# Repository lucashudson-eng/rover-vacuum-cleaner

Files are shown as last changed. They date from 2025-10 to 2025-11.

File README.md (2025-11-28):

# rover

Autonomous robotic rover designed for navigation and task execution, inspired by smart vacuum cleaners.

## Main Components

- [BTT PI 2](https://pt.aliexpress.com/item/1005006869449371.html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)
- [ESP32-S3 Nano](https://pt.aliexpress.com/item/1005007291319086.html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)
- [Lidar 2D 360º LD14P](https://pt.aliexpress.com/item/1005008670123046.html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)
- [N20 DC Motor 6V 500RPM w/ Magnetic Encoders](https://pt.aliexpress.com/item/1005004999529855.html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)
- [Pololu Motor Driver TB6612FNG](https://www.pololu.com/product/713)
- [IMU 6-DOF MPU-6050](https://pt.aliexpress.com/item/1005008569435439.html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)
- [Wheels 65mm](https://pt.aliexpress.com/item/1005005293126427.html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)
- [Chassi 4WD](https://pt.aliexpress.com/item/1005007026658421.html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)
- [Camera OV5647](https://pt.aliexpress.com/item/1005006279352733.html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)
- [3x ToF VL53L1X/TOF400C](https://pt.aliexpress.com/item/1005009534829792.html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)
- [I2C Multiplexer TCA9548A](https://pt.aliexpress.com/item/1005004996004241.html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)
- [Buck Step Down 6V 2.2A LM317](https://pt.aliexpress.com/item/1005006299002383.html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)
-  [I2C Power Monitoring INA219](https://pt.aliexpress.com/item/1005007533576335.html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)
- Battery 3s 2500mah

## Auxiliary Components

- [2P/4P/5P/6P JST 2.54mm Right Angle Pin Connector](https://pt.aliexpress.com/item/33008489410.html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)
- [2P/4P/5P/6P JST 2.54mm Housing](https://pt.aliexpress.com/item/1005007449862216.html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)
- [4P JST 2.54mm Extension Line](https://pt.aliexpress.com/item/1005007492397255.html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)
- [Battery Velcro Strap](https://shopee.com.br/Cinta-Correia-Velcro-Para-Bateria-Lipo-Drone-Aeromodelo-automodelo-25cm-i.389375152.9818950596)
- [PCB Universal Board Single Sid 7x9cm](https://pt.aliexpress.com/item/1005007720411113.html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)
- [PTH Resistors 1/4W 3.3K/6.2K/10K](https://pt.aliexpress.com/item/32968455454.html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)
- [M2.5/M3 Hex Nylon Standoff Spacer](https://pt.aliexpress.com/item/32862529967.html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)
- [12V Round Rocker Switch LED](https://pt.aliexpress.com/item/1005007561730939.html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)
- [N20 Motor Mount](https://pt.aliexpress.com/item/1005007027114123.html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)

## Pinout

### Battery
- Cell 1 - A0 (GPIO1)
- Cell 1+2 - A1 (GPIO2)

### ISR

- 3xVL6180X - A2 (GPIO3)
- MPU6050 - A3 (GPIO4)
- Motor Encoder Back Left C1 - D2 (GPIO5)
- Motor Encoder Back Left C2 - D3 (GPIO6)
- Motor Encoder Back Right C2 - D4 (GPIO7)
- Motor Encoder Back Right C1 - D5 (GPIO8)

### Motor Driver

- PWMA - D6 (GPIO8)
- AIN2 - D7 (GPIO9)
- AIN1 - D8 (GPIO10)
- STBY - D9 (GPIO18)
- BIN1 - D10 (GPIO21)
- BIN2 - D11 (GPIO38)
- PWMB - D12 (GPIO47)

### I2C (MPU6050, TCA9548A (3xVL6180X), INA219)

- SDA - A4 (GPIO11)
- SCL - A5 (GPIO12)

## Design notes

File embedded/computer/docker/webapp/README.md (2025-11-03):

# Rover Vacuum Cleaner - Sistema Embarcado

Sistema web embarcado para controle de rover aspirador autônomo, desenvolvido com React + Vite no frontend e Flask no backend, otimizado para recursos limitados.

## Estrutura do Projeto

```
webapp/
├── frontend/          # Aplicação React + Vite
│   ├── src/           # Código fonte React
│   │   ├── components/ # Componentes React
│   │   ├── App.jsx    # Componente principal
│   │   └── main.jsx   # Ponto de entrada
│   ├── public/        # Arquivos estáticos
│   ├── package.json   # Dependências React
│   ├── server.js     # Servidor Express para produção
│   └── vite.config.js # Configuração Vite
├── backend/           # API Flask
│   ├── requirements.txt # Dependências Python
│   └── app.py         # API Flask
├── Dockerfile         # Build otimizado para Ubuntu 24
├── start.sh          # Script de inicialização interno
└── README.md         # Este arquivo
```

## Como Executar

### Comandos Docker

```bash
# Construir imagem
docker build -t rover-webapp .

# Executar container
docker run -d --name rover-webapp \
  -p 0.0.0.0:3000:3000 \
  -p 0.0.0.0:8000:8000 \
  --device=/dev/video0:/dev/video0 \
  --privileged \
  rover-webapp

# Parar container
docker stop rover-webapp && docker rm rover-webapp
```

### Acessos

- **Frontend:** http://localhost:3000
- **Backend API:** http://localhost:8000
- **Health Check Frontend:** http://localhost:3000/api/health
- **Health Check Backend:** http://localhost:8000/api/health
- **Stream da Câmera:** http://localhost:8000/video_feed
- **Status da Câmera:** http://localhost:8000/api/camera/status

### Acesso Externo (Celular/Outros Dispositivos)

Para acessar de outros dispositivos na rede local:

1. **Descobrir o IP da máquina:**
   ```bash
   hostname -I
   ```

2. **Parar e recriar o container com o IP correto:**
   ```bash
   docker stop rover-webapp && docker rm rover-webapp
   docker run -d --name rover-webapp \
     -p 0.0.0.0:3000:3000 \
     -p 0.0.0.0:8000:8000 \
     --device=/dev/video0:/dev/video0 \
     --privileged \
     rover-webapp
   ```

4. **Acessar do celular:**
   - URL: `http://SEU_IP:3000`
   - Exemplo: `http://192.168.1.100:3000`

## Variáveis de Ambiente

### Frontend

- `VITE_BACKEND_URL`: URL do backend usada pelo frontend. Se não definida, o frontend usa automaticamente `http://<hostname_atual>:8000`.

Exemplos:

```bash
# Usando localhost durante desenvolvimento
export VITE_BACKEND_URL=http://localhost:8000

# Usando IP da sua BTT/host na LAN
export VITE_BACKEND_URL=http://192.168.1.100:8000
```

Ao usar Docker, você pode passar com `-e VITE_BACKEND_URL=...` se estiver executando o frontend em modo dev. No build de produção já é feito o inferimento automático pelo hostname.

## Configuração da Câmera

### Pré-requisitos
- Câmera USB conectada ao sistema
- Dispositivo `/dev/video0` disponível
- Permissões adequadas para acesso à câmera

### Configuração Docker
O `docker-compose.yml` já está configurado para:
- Mapear o dispositivo `/dev/video0` para o container
- Executar com privilégios necessários para acesso à câmera
- Configurar variáveis de ambiente para display

## Desenvolvimento

### Frontend (React + Vite)
- Framework: React 18 + Vite
- UI: Componentes responsivos com CSS moderno
- Porta: 3000
- Build otimizado para produção

### Backend (Python 3.10-slim)
- Framework: Flask
- Porta: 8000
- API REST para controle do rover
- CORS habilitado para frontend

## Funcionalidades

### Interface Web
- **Dashboard responsivo** com navegação intuitiva
- **Controle do rover** via interface web
- **Mapa de navegação** em tempo real
- **Câmera integrada** para monitoramento com streaming MJPEG
- **Configurações** do sistema
- **Menu adaptativo** para desktop e mobile

### Sistema de Câmera
- **Streaming MJPEG** em tempo real da câmera `/dev/video0`
- **Controles de câmera** (rotação, zoom)
- **Status da câmera** com verificação automática
- **Interface responsiva** para visualização do vídeo
- **Qualidade otimizada** para sistemas embarcados

### Otimizações para Embarcado
- **Build multi-stage** reduz tamanho da imagem
- **Usuário não-root** para segurança
- **Recursos mínimos** necessários
- **Inicialização rápida** com script otimizado
- **Interface responsiva** para diferentes telas

## Próximos Passos

1. Implementar comunicação serial com rover
2. Adicionar controle de motores
3. Implementar sistema de navegação
4. Adicionar sensores de obstáculos
5. Configurar telemetria em tempo real

## Vantagens da Aplicação Embarcada

✅ **Eficiência:** Uma única imagem Docker  
✅ **Simplicidade:** Um container para gerenciar  
✅ **Otimização:** Build multi-stage reduz tamanho final  
✅ **Deploy:** Mais fácil para sistemas embarcados  
✅ **Recursos:** Menor consumo de memória e CPU  

## Comandos Úteis

```bash
# Ver logs do container
docker logs rover-webapp -f

# Executar comandos no container
docker exec -it rover-webapp bash

# Reconstruir a imagem
docker build -t rover-webapp . --no-cache

# Verificar tamanho da imagem
docker images rover-webapp

# Limpar containers parados
docker container prune

# Limpar imagens não utilizadas
docker image prune
```

## Troubleshooting

### Problemas Comuns

1. **Erro "Câmera não disponível":**
   ```bash
   # Verificar se a câmera está conectada
   ls -la /dev/video*
   
   # Testar acesso à câmera
   docker exec -it rover-webapp python3 -c "import cv2; cap = cv2.VideoCapture(0); print('OK' if cap.isOpened() else 'Erro')"
   ```

2. **Erro de permissão na câmera:**
   ```bash
   # Adicionar usuário ao grupo video
   sudo usermod -a -G video $USER
   # Reiniciar o sistema
   ```

3. **Container não inicia:**
   ```bash
   # Ver logs detalhados
   docker logs rover-webapp -f
   
   # Verificar se as portas estão livres
   sudo netstat -tulpn | grep :3000
   sudo netstat -tulpn | grep :8000
   ```

4. **Acesso externo não funciona:**
   ```bash
   # Verificar firewall
   sudo ufw status
   
   # Verificar se o container está escutando em 0.0.0.0
   docker port rover-webapp
   ```

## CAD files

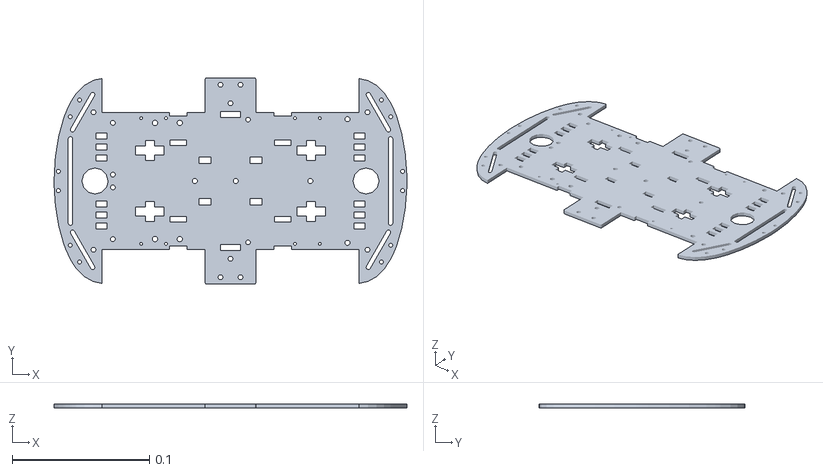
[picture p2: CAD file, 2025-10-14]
rover_vacuum_cleaner/models/rover/meshes/base_link.STL
0.257 x 0.15 x 0.003

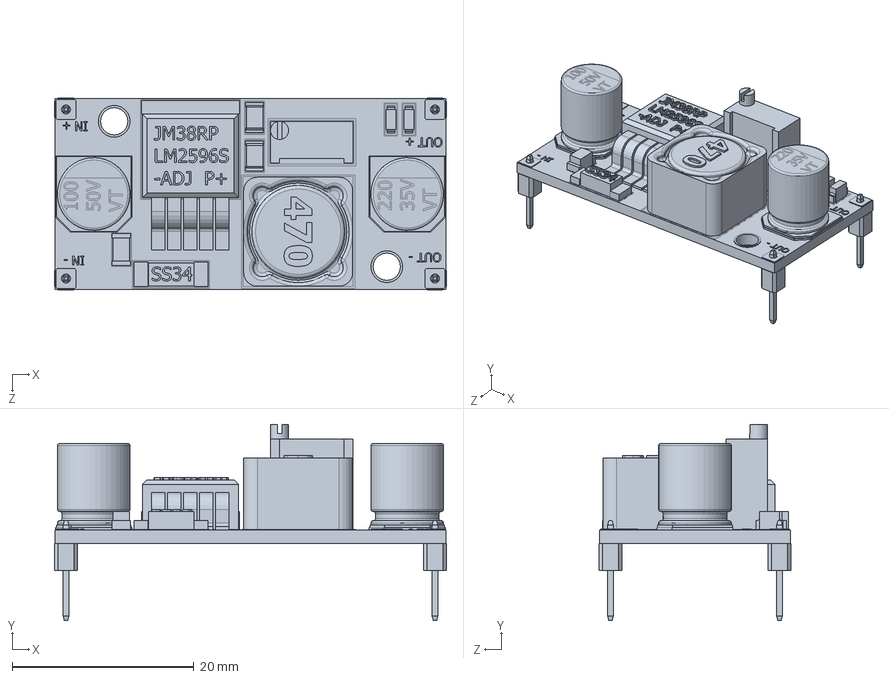
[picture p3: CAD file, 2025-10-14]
solidworks/LM2596.SLDPRT
43.1 x 21.6 x 21.1 mm

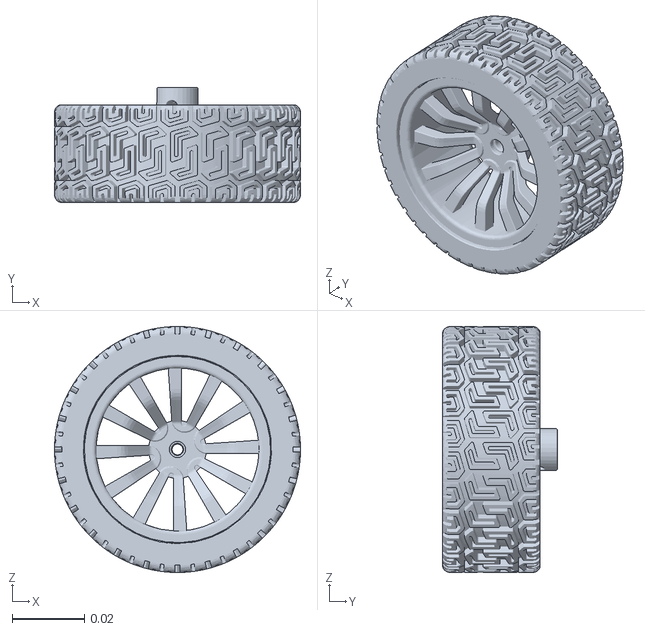
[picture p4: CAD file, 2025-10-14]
rover_vacuum_cleaner/models/rover/meshes/Wheel_Link_BR.STL
0.068 x 0.0318 x 0.068

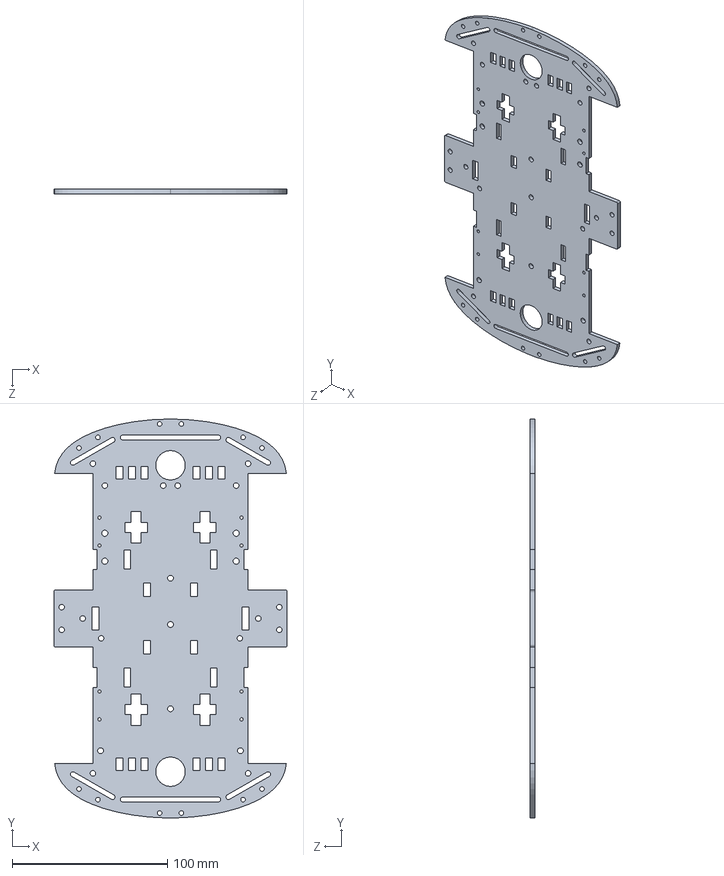
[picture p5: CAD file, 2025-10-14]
solidworks/Chassi.SLDPRT
150.0 x 257.0 x 3.00 mm

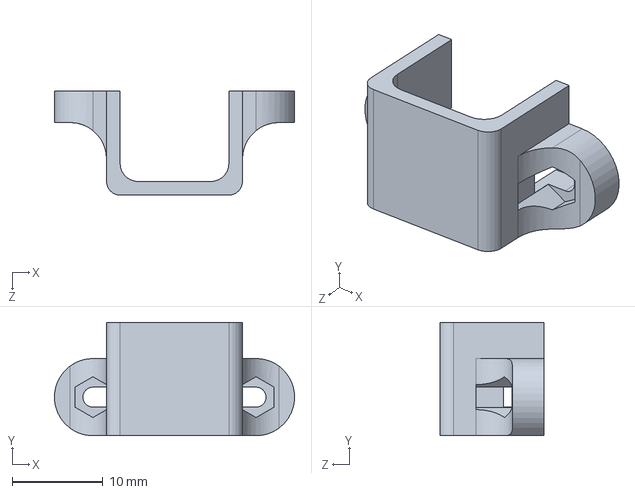
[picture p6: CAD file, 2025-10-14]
solidworks/N20_Mount.SLDPRT
26.5 x 12.5 x 11.5 mm

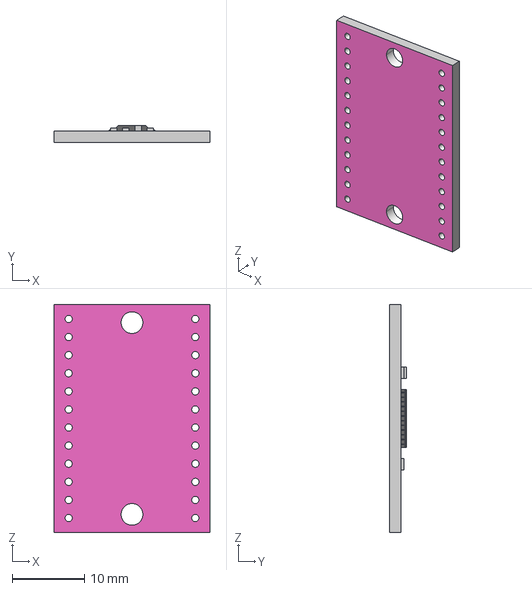
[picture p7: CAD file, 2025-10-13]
solidworks/TCA9548A.stp
21.5 x 2.40 x 31.5 mm

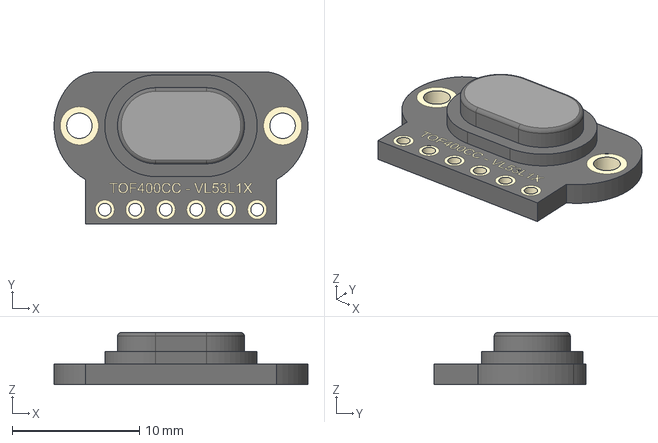
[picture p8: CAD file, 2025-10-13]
solidworks/VL53L1X.step
20.0 x 12.0 x 4.10 mm

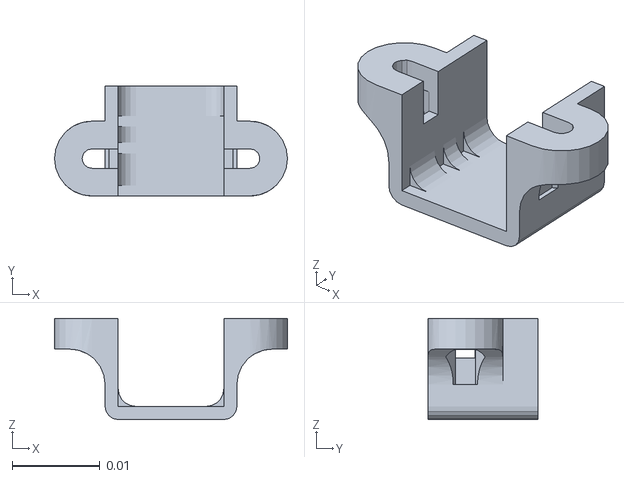
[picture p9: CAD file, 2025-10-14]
rover_vacuum_cleaner/models/rover/meshes/Mount_Link_FR.STL
0.0265 x 0.0125 x 0.0115

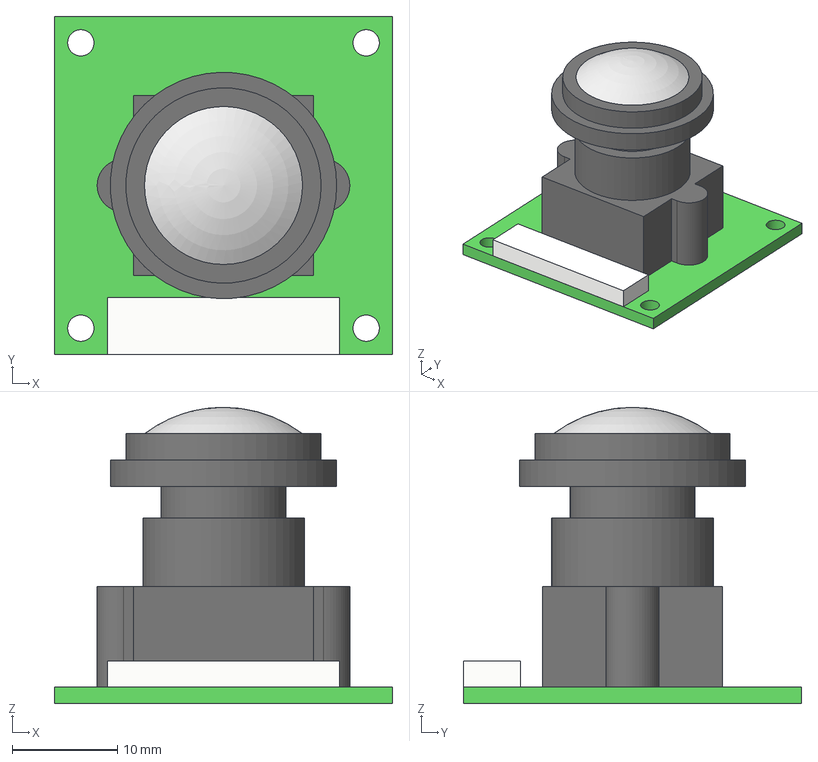
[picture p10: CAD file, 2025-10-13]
solidworks/OV5647.step
32.1 x 32.1 x 28.2 mm
Lens
Connector
Lense frame
PCB
Camera Body

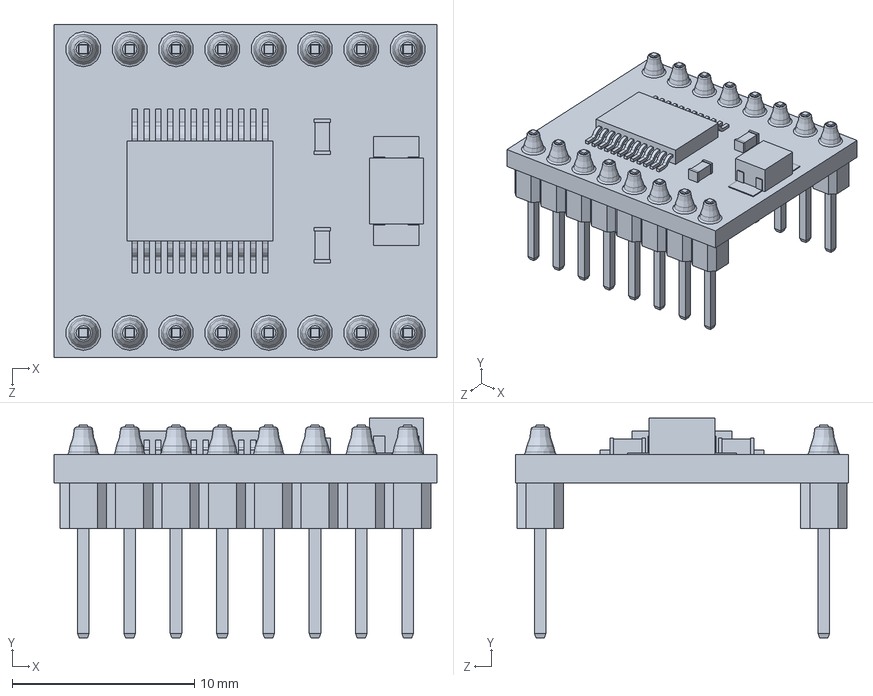
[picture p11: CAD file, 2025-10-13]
solidworks/TB6612FNG.SLDPRT
21.0 x 12.1 x 18.2 mm

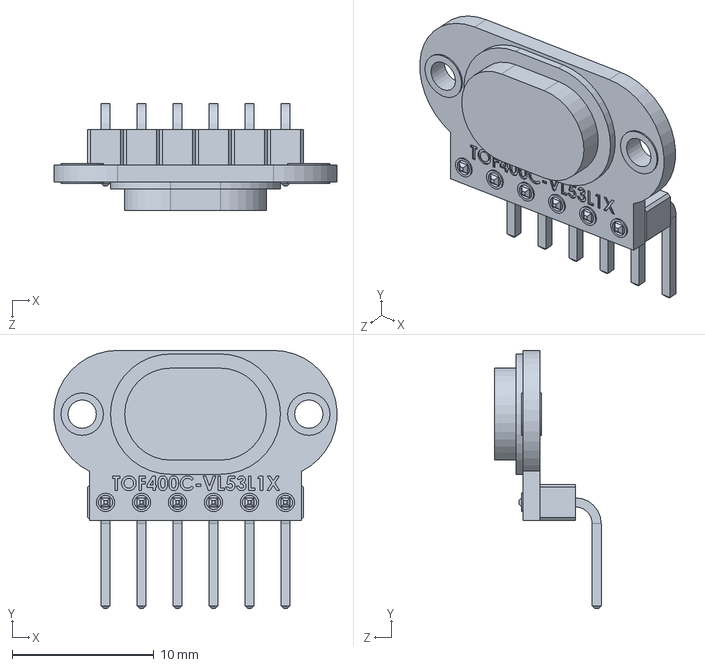
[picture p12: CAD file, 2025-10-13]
solidworks/TOF400C.SLDPRT
20.0 x 18.2 x 7.52 mm

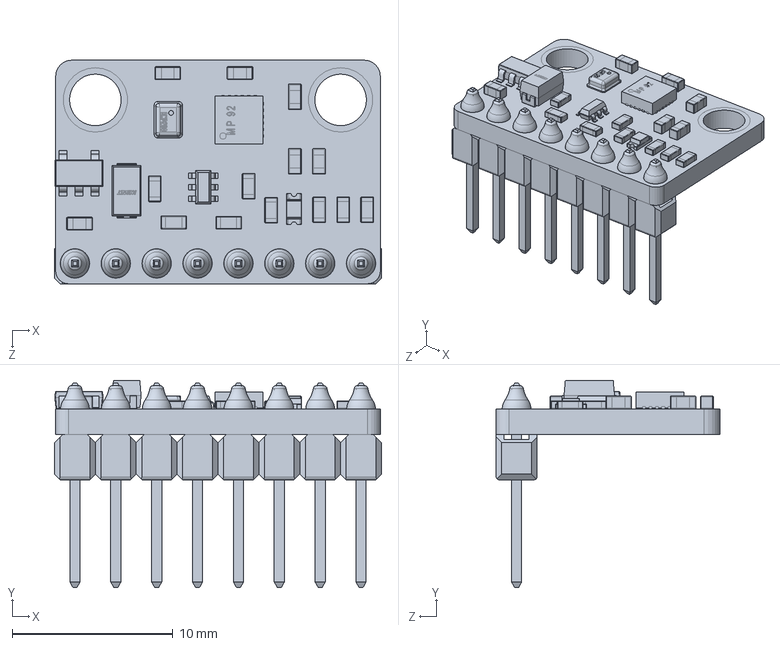
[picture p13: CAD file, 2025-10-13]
solidworks/GY_91.SLDPRT
20.3 x 12.9 x 13.9 mm

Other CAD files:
rover_vacuum_cleaner/models/rover/meshes/Wheel_Link_BL.STL
rover_vacuum_cleaner/models/rover/meshes/Wheel_Link_FR.STL
rover_vacuum_cleaner/models/rover/meshes/Wheel_Link_FL.STL
rover_vacuum_cleaner/models/rover/meshes/Mount_Link_BR.STL
rover_vacuum_cleaner/models/rover/meshes/Mount_Link_FL.STL
rover_vacuum_cleaner/models/rover/meshes/Mount_Link_BL.STL
rover_vacuum_cleaner/models/rover/meshes/LD14P_Link.STL

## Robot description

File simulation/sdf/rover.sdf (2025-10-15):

<?xml version="1.0" ?>
<sdf version="1.10">
    <world name="indoor_house_world">
        <physics name="1ms" type="ignored">
            <max_step_size>0.001</max_step_size>
            <real_time_factor>1.0</real_time_factor>
        </physics>
        <plugin filename="gz-sim-physics-system" name="gz::sim::systems::Physics">
        </plugin>
        <plugin filename="gz-sim-user-commands-system" name="gz::sim::systems::UserCommands">
        </plugin>
        <plugin filename="gz-sim-scene-broadcaster-system" name="gz::sim::systems::SceneBroadcaster">
        </plugin>
        <plugin filename="gz-sim-imu-system" name="gz::sim::systems::Imu">
        </plugin>
        <plugin filename="gz-sim-sensors-system" name="gz::sim::systems::Sensors">
            <render_engine>ogre2</render_engine>
        </plugin>

        <light type="directional" name="sun">
            <cast_shadows>true</cast_shadows>
            <pose>0 0 10 0 0 0</pose>
            <diffuse>0.9 0.9 0.9 1</diffuse>
            <specular>0.3 0.3 0.3 1</specular>
            <attenuation>
                <range>1000</range>
                <constant>0.9</constant>
                <linear>0.01</linear>
                <quadratic>0.001</quadratic>
            </attenuation>
            <direction>0 0 -1</direction>
        </light>

        <model name="ground_plane">
            <static>true</static>
            <link name="link">
                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
            </link>
        </model>

        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
        <model name="wall_north">
            <static>true</static>
            <pose>0 3.5 0.8 0 0 0</pose>
            <link name="link">
                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
            </link>
        </model>

        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
        <model name="wall_south">
            <static>true</static>
            <pose>0 -3.5 0.8 0 0 0</pose>
            <link name="link">
                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
            </link>
        </model>

        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
        <model name="wall_east">
            <static>true</static>
            <pose>3.5 0 0.8 0 0 0</pose>
            <link name="link">
                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
            </link>
        </model>

        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
        <model name="wall_west">
            <static>true</static>
            <pose>-3.5 0 0.8 0 0 0</pose>
            <link name="link">
                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
            </link>
        </model>

        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
        <model name="wall_divider_1">
            <static>true</static>
            <pose>0 0 0.8 0 0 0</pose>
            <link name="link">
                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
            </link>
        </model>

        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
        <model name="wall_divider_2">
            <static>true</static>
            <pose>1.5 0 0.8 0 0 0</pose>
            <link name="link">
                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
            </link>
        </model>

        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
        <model name="wall_divider_3">
            <static>true</static>
            <pose>0 1.5 0.8 0 0 0</pose>
            <link name="link">
                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
            </link>
        </model>

        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
        <model name="table_living_room">
            <static>true</static>
            <pose>-1.2 -1.2 0.2 0 0 0</pose>
            <link name="link">
                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
            </link>
        </model>

        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
        <model name="table_kitchen">
            <static>true</static>
            <pose>0.8 1.2 0.2 0 0 0</pose>
            <link name="link">
                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
            </link>
        </model>

        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
        <model name="bed">
            <static>true</static>
            <pose>2.5 -0.5 0.15 0 0 0</pose>
            <link name="link">
                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
            </link>
        </model>

        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
        <model name="wardrobe">
            <static>true</static>
            <pose>2.5 1.2 0.5 0 0 0</pose>
            <link name="link">
                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
            </link>
        </model>

        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
        <model name="sofa">
            <static>true</static>
            <pose>-1.8 -1.8 0.2 0 0 0</pose>
            <link name="link">
                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
            </link>
        </model>

        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
        <model name="chair">
            <static>true</static>
            <pose>-0.8 -1.8 0.15 0 0 0</pose>
            <link name="link">
                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
            </link>
        </model>

        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
        <model name="tv_stand">
            <static>true</static>
            <pose>-2.8 -1.2 0.15 0 0 0</pose>
            <link name="link">
                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
            </link>
        </model>

        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
        <model name="refrigerator">
            <static>true</static>
            <pose>2.8 1.8 0.5 0 0 0</pose>
            <link name="link">
                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
            </link>
        </model>

        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
        <model name="stove">
            <static>true</static>
            <pose>1.2 1.8 0.15 0 0 0</pose>
            <link name="link">
                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
            </link>
        </model>

        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
        <model name="sink">
            <static>true</static>
            <pose>0.4 1.8 0.2 0 0 0</pose>
            <link name="link">
                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
            </link>
        </model>

        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
        <model name="dresser">
            <static>true</static>
            <pose>2.0 -1.8 0.25 0 0 0</pose>
            <link name="link">
                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
            </link>
        </model>

        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
        <model name="nightstand">
            <static>true</static>
            <pose>3.2 -0.5 0.15 0 0 0</pose>
            <link name="link">
                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
            </link>
        </model>

        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
        <model name="bathroom_sink">
            <static>true</static>
            <pose>1.8 2.8 0.2 0 0 0</pose>
            <link name="link">
                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
            </link>
        </model>

        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
        <model name="toilet">
            <static>true</static>
            <pose>2.5 2.8 0.15 0 0 0</pose>
            <link name="link">
                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
            </link>
        </model>

        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
        <model name="plant_pot">
            <static>true</static>
            <pose>0.5 0.5 0.1 0 0 0</pose>
            <link name="link">
                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
            </link>
        </model>

        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
        <model name="plant_pot_2">
            <static>true</static>
            <pose>-0.5 -0.5 0.1 0 0 0</pose>
            <link name="link">
                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
            </link>
        </model>

        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
        <model name="small_table">
            <static>true</static>
            <pose>0.3 0.3 0.15 0 0 0</pose>
            <link name="link">
                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
            </link>
        </model>

        <model name="rover">
            <link name="base_link">
            <pose relative_to='__model__'>1 0 0.05 0 0 0</pose>

            <sensor name="imu_sensor" type="imu">
                <always_on>1</always_on>
                <update_rate>100</update_rate>
                <visualize>true</visualize>
                <topic>imu</topic>
            </sensor>

            <inertial>
                <pose>2.04381831142401E-09 1.56408869429724E-17 -0.0015 0 0 0</pose>
                <mass>0.0757356843292425</mass>
                <inertia>
                <ixx>9.30542487791855E-05</ixx>
                <ixy>-1.72973378957802E-10</ixy>
                <ixz>-1.66079077298931E-21</ixz>
                <iyy>0.000382138338193282</iyy>
                <iyz>3.43912726365504E-23</iyz>
                <izz>0.000475078982714826</izz>
                </inertia>
            </inertial>
            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
            </link>

            <link name="LD14P_Link">
            <pose relative_to="base_link">-0.00012702 0 0.03845 0 0 0</pose>
            <inertial>
                <pose>0.015195 -9.1663E-05 -0.019909 0 0 0</pose>
                <mass>0.025443</mass>
                <inertia>
                <ixx>5.3011E-06</ixx>
                <ixy>-1.5024E-08</ixy>
                <ixz>1.2999E-09</ixz>
                <iyy>8.6464E-06</iyy>
                <iyz>-1.8484E-08</iyz>
                <izz>1.3337E-05</izz>
                </inertia>
            </inertial>
            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

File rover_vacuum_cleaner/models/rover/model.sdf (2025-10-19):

<?xml version="1.0" ?>
<sdf version="1.10">
    <model name="rover">
        <link name="base_link">

        <sensor name="imu_sensor" type="imu">
            <always_on>1</always_on>
            <update_rate>100</update_rate>
            <visualize>true</visualize>
            <topic>imu</topic>
            <gz_frame_id>rover/base_link</gz_frame_id>
        </sensor>

        <inertial>
            <pose>2.04381831142401E-09 1.56408869429724E-17 -0.0015 0 0 0</pose>
            <mass>0.0757356843292425</mass>
            <inertia>
            <ixx>9.30542487791855E-05</ixx>
            <ixy>-1.72973378957802E-10</ixy>
            <ixz>-1.66079077298931E-21</ixz>
            <iyy>0.000382138338193282</iyy>
            <iyz>3.43912726365504E-23</iyz>
            <izz>0.000475078982714826</izz>
            </inertia>
        </inertial>
        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
        </link>

        <link name="LD14P_Link">
        <pose relative_to="base_link">-0.00012702 0 0.03845 0 0 0</pose>
        <inertial>
            <pose>0.015195 -9.1663E-05 -0.019909 0 0 0</pose>
            <mass>0.025443</mass>
            <inertia>
            <ixx>5.3011E-06</ixx>
            <ixy>-1.5024E-08</ixy>
            <ixz>1.2999E-09</ixz>
            <iyy>8.6464E-06</iyy>
            <iyz>-1.8484E-08</iyz>
            <izz>1.3337E-05</izz>
            </inertia>
        </inertial>
        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

        <sensor name="LD14P_lidar" type="gpu_lidar">
            <topic>scan</topic>
            <update_rate>6</update_rate>
            <ray>
                <scan>
                    <horizontal>
                        <samples>360</samples>
                        <resolution>1</resolution>
                        <min_angle>0</min_angle>
                        <max_angle>6.28319</max_angle>
                    </horizontal>
                </scan>
                <range>
                    <min>0.1</min>
                    <max>8.0</max>
                    <resolution>0.01</resolution>
                </range>
                <noise>
                    <type>gaussian</type>
                    <mean>0.0</mean>
                    <stddev>0.05</stddev>
                </noise>
            </ray>
            <always_on>1</always_on>
            <visualize>true</visualize>
        </sensor>
        </link>

        <joint name="LD14P" type="fixed">
        <parent>base_link</parent>
        <child>LD14P_Link</child>
        </joint>


        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
        <link name="Mount_Link_FR">
        <pose relative_to="base_link">0.055873 -0.05 -0.0092866 0 0 0</pose>
        <inertial>
            <pose>-2.8937E-05 0.0057418 0.00032322 0 0 0</pose>
            <mass>0.00088951</mass>
            <inertia>
            <ixx>2.4974E-08</ixx>
            <ixy>-3.6241E-11</ixy>
            <ixz>-9.203E-11</ixz>
            <iyy>6.2294E-08</iyy>
            <iyz>1.983E-09</iyz>
            <izz>5.9248E-08</izz>
            </inertia>
        </inertial>
        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
        </link>

        <joint name="Mount_FR" type="fixed">
        <parent>base_link</parent>
        <child>Mount_Link_FR</child>
        </joint>

        <link name="Motor_Link_FR">
        <pose relative_to="Mount_Link_FR">7.6341E-05 -0.0092 0.0012869 0 0 0</pose>
        <inertial>
            <pose>-6.0305E-05 0.026341 0.00088289 0 0 0</pose>
            <mass>0.0028388</mass>
            <inertia>
            <ixx>5.2064E-08</ixx>
            <ixy>8.1692E-12</ixy>
            <ixz>-2.1321E-10</ixz>
            <iyy>5.1223E-08</iyy>
            <iyz>9.4713E-12</iyz>
            <izz>5.0388E-08</izz>
            </inertia>
        </inertial>
        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
        </link>

        <joint name="Motor_FR" type="fixed">
        <parent>Mount_Link_FR</parent>
        <child>Motor_Link_FR</child>
        </joint>
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

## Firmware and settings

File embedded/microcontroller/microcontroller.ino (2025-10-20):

#include <Wire.h>
#include <MadgwickAHRS.h>
#include "freertos/FreeRTOS.h"
#include "freertos/task.h"
#include "freertos/queue.h"
#include "MPU9250.h"

// ----- I2C CONFIGURATION -----
#define I2C_SDA_PIN 21
#define I2C_SCL_PIN 22
#define I2C_FREQ 400000

// ----- MPU9250 CONFIGURATION -----
#define MPU_INT_PIN 23

// ----- ENCODERS PINS -----
#define ENC_LEFT_A      23
#define ENC_LEFT_B      22
#define ENC_RIGHT_A     18
#define ENC_RIGHT_B     19

// ----- ROBOT PARAMETERS -----
#define WHEEL_RADIUS    0.065/2    // meters
#define WHEEL_BASE      0.138     // meters
#define CPR             840       // counts per revolution (7x4xreduction)
#define UPDATE_PERIOD_MS 100      // odometry and IMU update interval

// ----- GLOBAL VARIABLES -----
// MPU9250
Madgwick filter;

QueueHandle_t mpu_queue = NULL;

unsigned long lastReadTime = 0;

float ax, ay, az;  // Accelerometer (g)
float gx, gy, gz;  // Gyroscope (deg/s)
float mx, my, mz;  // Magnetometer (µT)

float roll, pitch, yaw;

MPU9250 imu;

// ENCODERS
volatile int32_t count_left = 0;
volatile int32_t count_right = 0;

volatile int lastLA = 0, lastLB = 0;
volatile int lastRA = 0, lastRB = 0;

// Robot pose
float x = 0.0, y = 0.0, theta = 0.0;

// Estimated velocities
float v = 0.0;      // linear (m/s)
float omega = 0.0;   // angular (rad/s)

// ----- IMU MPU9250 ISR -----
void IRAM_ATTR mpu_intr_handler() {
    BaseType_t xHigherPriorityTaskWoken = pdFALSE;
    uint32_t dummy = 1;
    xQueueSendFromISR(mpu_queue, &dummy, &xHigherPriorityTaskWoken);
    if (xHigherPriorityTaskWoken) {
        portYIELD_FROM_ISR();
    }
}

// ----- ENCODER QUADRATURE X4 ISR -----
void IRAM_ATTR encoder_isr_handler() {
  int a = digitalRead(ENC_LEFT_A);
  int b = digitalRead(ENC_LEFT_B);
  int transition = (lastLA << 3) | (lastLB << 2) | (a << 1) | b;
  
  switch (transition) {
    case 0b0001: case 0b0111: case 0b1110: case 0b1000:
      count_left++; 
      break;
    case 0b0010: case 0b0100: case 0b1101: case 0b1011:
      count_left--; 
      break;
    default: 
      break;
  }
  lastLA = a;
  lastLB = b;
}

void IRAM_ATTR encoder_right_isr_handler() {
  int a = digitalRead(ENC_RIGHT_A);
  int b = digitalRead(ENC_RIGHT_B);
  int transition = (lastRA << 3) | (lastRB << 2) | (a << 1) | b;
  
  switch (transition) {
    case 0b0001: case 0b0111: case 0b1110: case 0b1000:
      count_right++; 
      break;
    case 0b0010: case 0b0100: case 0b1101: case 0b1011:
      count_right--; 
      break;
    default: 
      break;
  }
  lastRA = a;
  lastRB = b;
}

// ----- FREERTOS IMU TASK -----
void imu_task(void *parameter) {
  Serial.println("IMU task started");
  uint32_t dummy;
  
  while (true) {
    // Wait for interrupt signal (same as ESP-IDF)
    if (xQueueReceive(mpu_queue, &dummy, portMAX_DELAY)) {
      unsigned long now = micros();
      float dt = (now - lastReadTime) / 1000000.0f;
      lastReadTime = now;
      
      // Read IMU data (accelerometer + gyroscope) in one transaction
      bool dataValid = imu.readIMU(&ax, &ay, &az, &gx, &gy, &gz);
      
      // Read magnetometer data
      bool magValid = imu.readMag(&mx, &my, &mz);
      
      if (dataValid) {
        // Update Madgwick filter
        if (magValid) {
          // Use full 9DOF data (IMU + magnetometer)
          filter.update(gx, gy, gz, ax, ay, az, mx, my, mz);
        } else {
          // Fallback to IMU-only mode
          filter.updateIMU(gx, gy, gz, ax, ay, az);
        }
        
        // Get Euler angles (in degrees)
        roll = filter.getRoll();
        pitch = filter.getPitch();
        yaw = filter.getYaw();
        
        // Calculate actual sampling frequency
        float freq = (dt > 0) ? (1.0f / dt) : 0;
        
        // Display results
        Serial.print("f: ");
        Serial.print(freq, 2);
        Serial.print(" Hz  Roll: ");
        Serial.print(roll, 2);
        Serial.print("  Pitch: ");
        Serial.print(pitch, 2);
        Serial.print("  Yaw: ");
        Serial.print(yaw, 2);
        Serial.print("  Mag: ");
        Serial.println(magValid ? "OK" : "FAIL");
      } else {
        Serial.println("Failed to read IMU data");
      }
    }
  }
}

// ----- ODOMETRY FUNCTION -----
void update_odometry(int32_t delta_left, int32_t delta_right, float dt) {
  float dist_per_count = 2.0 * PI * WHEEL_RADIUS / CPR;

  float d_left  = delta_left * dist_per_count;
  float d_right = delta_right * dist_per_count;

  float ds = (d_right + d_left) / 2.0;
  float dtheta = (d_right - d_left) / WHEEL_BASE;

  x += ds * cos(theta + dtheta / 2.0);
  y += ds * sin(theta + dtheta / 2.0);
  theta += dtheta;

  // Velocities
  v = ds / dt;
  omega = dtheta / dt;
}

// ----- FREERTOS ODOMETRY TASK -----
void odometry_task(void *parameter) {
  int32_t last_count_left = 0;
  int32_t last_count_right = 0;
  
  Serial.println("Odometry task started");
  
  while (true) {
    // Wait for the specified period
    vTaskDelay(pdMS_TO_TICKS(UPDATE_PERIOD_MS));
    
    // Calculate deltas
    int32_t delta_left  = count_left - last_count_left;
    int32_t delta_right = count_right - last_count_right;

    last_count_left  = count_left;
    last_count_right = count_right;

    float dt = UPDATE_PERIOD_MS / 1000.0; // time in seconds

    // Update odometry
    update_odometry(delta_left, delta_right, dt);

    // Print odometry
    Serial.print("Pose: x=");
    Serial.print(x, 4);
    Serial.print(" m, y=");
    Serial.print(y, 4);
    Serial.print(" m, theta=");
    Serial.print(theta, 3);
    Serial.println(" rad");
    
    Serial.print("Velocity: v=");
    Serial.print(v, 4);
    Serial.print(" m/s, omega=");
    Serial.print(omega, 4);
    Serial.println(" rad/s");
    
    Serial.print("Counts: Left=");
    Serial.print(count_left);
    Serial.print(" Right=");
    Serial.println(count_right);
    Serial.println();
  }
}

void setup() {
  Serial.begin(115200);

  // Initialize I2C
  Wire.begin(I2C_SDA_PIN, I2C_SCL_PIN);
  Wire.setClock(I2C_FREQ);
  Serial.println("I2C initialized");
  
  // Initialize MPU9250
  if (!imu.mpu9250_init()) {
    Serial.println("Failed to initialize MPU9250!");
    while (1) {
      delay(1000);
    }
  }
  if (!imu.ak8963_init()) {
    Serial.println("Failed to initialize AK8963 magnetometer!");
    // Continue without magnetometer
  }

  // Create queue for IMU interrupt communication
  mpu_queue = xQueueCreate(10, sizeof(uint32_t));
  if (mpu_queue == NULL) {
    Serial.println("Failed to create queue");
    return;
  }
  Serial.println("Queue created");
  
  // Configure encoder pins
  pinMode(ENC_LEFT_A, INPUT_PULLUP);
  pinMode(ENC_LEFT_B, INPUT_PULLUP);
  pinMode(ENC_RIGHT_A, INPUT_PULLUP);
  pinMode(ENC_RIGHT_B, INPUT_PULLUP);
  // Configure IMU interrupt pin
  pinMode(MPU_INT_PIN, INPUT_PULLUP);
  
  // Initialize last states
  lastLA = digitalRead(ENC_LEFT_A);
  lastLB = digitalRead(ENC_LEFT_B);
  lastRA = digitalRead(ENC_RIGHT_A);
  lastRB = digitalRead(ENC_RIGHT_B);
  
  // Attach interrupts
  attachInterrupt(digitalPinToInterrupt(ENC_LEFT_A), encoder_isr_handler, CHANGE);
  attachInterrupt(digitalPinToInterrupt(ENC_LEFT_B), encoder_isr_handler, CHANGE);
  attachInterrupt(digitalPinToInterrupt(ENC_RIGHT_A), encoder_right_isr_handler, CHANGE);
  attachInterrupt(digitalPinToInterrupt(ENC_RIGHT_B), encoder_right_isr_handler, CHANGE);
  attachInterrupt(digitalPinToInterrupt(MPU_INT_PIN), mpu_intr_handler, RISING);

  // Initialize Madgwick filter
  filter.begin(UPDATE_PERIOD_MS);
  Serial.println("Madgwick filter initialized");
  
  // Initialize timing
  lastReadTime = micros();
  
  // Create FreeRTOS task for IMU processing
  xTaskCreate(
    imu_task,              // Task function
    "IMUTask",             // Task name
    4096,                  // Stack size (words)
    NULL,                  // Task parameters
    1,                     // Task priority
    NULL                   // Task handle
  );

  // Create FreeRTOS task for odometry processing
  xTaskCreate(
    odometry_task,           // Task function
    "OdometryTask",          // Task name
    2048,                    // Stack size (words)
    NULL,                    // Task parameters
    1,                       // Task priority
    NULL                     // Task handle
  );
}

void loop() {
  delay(1000); // Small delay to prevent watchdog reset
}

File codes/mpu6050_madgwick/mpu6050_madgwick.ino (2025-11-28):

/*
 * IMU 6DOF with Madgwick AHRS for Arduino ESP32
 * Uses MPU6050 IMU with Madgwick filter for orientation estimation
 * Custom MPU6050 implementation using Wire library
 * 
 * Hardware:
 * - Arduino Nano ESP32 Dev Board
 * - MPU6050 6DOF IMU (Accelerometer + Gyroscope)
 * 
 * Pin Configuration:
 * - SDA: GPIO A4 (default)
 * - SCL: GPIO A5 (default)
 * - INT: GPIO A3 (optional, for interrupt-driven reading)
 * 
 * Libraries Required:
 * - MadgwickAHRS (by Paul Stoffregen)
 * - Wire (built-in)
 */

#include <Wire.h>
#include <MadgwickAHRS.h>
#include "freertos/FreeRTOS.h"
#include "freertos/task.h"
#include "freertos/queue.h"
#include "MPU6050.h"

// ----- INTERRUPT CONFIGURATION -----
#define INT_PIN A3

// ----- SAMPLING CONFIGURATION -----
#define SAMPLE_RATE_HZ 100
#define MICROS_PER_READING (1000000 / SAMPLE_RATE_HZ)

// ----- GLOBAL VARIABLES -----
Madgwick filter;

// Queue for communication between interrupt and task
QueueHandle_t mpu_queue = NULL;

// Timing variables
unsigned long lastReadTime = 0;

// Data storage
float ax, ay, az;  // Accelerometer (g)
float gx, gy, gz;  // Gyroscope (deg/s)

// Orientation results
float roll, pitch, yaw;

// Driver da IMU
MPU6050 imu;

// ----- INTERRUPT HANDLER -----
void IRAM_ATTR mpu_intr_handler() {
    BaseType_t xHigherPriorityTaskWoken = pdFALSE;
    uint32_t dummy = 1;
    xQueueSendFromISR(mpu_queue, &dummy, &xHigherPriorityTaskWoken);
    if (xHigherPriorityTaskWoken) {
        portYIELD_FROM_ISR();
    }
}

// ----- INTERRUPT PIN CONFIGURATION -----
bool setup_interrupt_pin() {
    pinMode(INT_PIN, INPUT_PULLUP);
    attachInterrupt(digitalPinToInterrupt(INT_PIN), mpu_intr_handler, RISING);
    return true;
}

// ----- FREERTOS TASK FOR IMU PROCESSING -----
void imu_task(void *parameter) {
    Serial.println("IMU task started");
    uint32_t dummy;
    
    while (true) {
        // Wait for interrupt signal (same as ESP-IDF)
        if (xQueueReceive(mpu_queue, &dummy, portMAX_DELAY)) {
            unsigned long now = micros();
            float dt = (now - lastReadTime) / 1000000.0f;
            lastReadTime = now;
            
            // Read IMU data (accelerometer + gyroscope) in one transaction
            bool dataValid = imu.readIMU(&ax, &ay, &az, &gx, &gy, &gz);
            
            if (dataValid) {
                // Update Madgwick filter with IMU-only mode (6DOF)
                filter.updateIMU(gx, gy, gz, ax, ay, az);
                
                // Get Euler angles (in degrees)
                roll = filter.getRoll();
                pitch = filter.getPitch();
                yaw = filter.getYaw();
                
                // Calculate actual sampling frequency
                float freq = (dt > 0) ? (1.0f / dt) : 0;
                
                // Display results
                Serial.print("f: ");
                Serial.print(freq, 2);
                Serial.print(" Hz  Roll: ");
                Serial.print(roll, 2);
                Serial.print("  Pitch: ");
                Serial.print(pitch, 2);
                Serial.print("  Yaw: ");
                Serial.println(yaw, 2);
            } else {
                Serial.println("Failed to read IMU data");
            }
        }
    }
}

// ----- ARDUINO SETUP -----
void setup() {
    Serial.begin(115200);
    Serial.println("IMU 6DOF with Madgwick AHRS - Starting...");
    
    // Initialize I2C
    Wire.begin();
    Serial.println("I2C initialized");
    
    // Initialize MPU6050
    if (!imu.mpu6050_init()) {
        Serial.println("Failed to initialize MPU6050!");
        while (1) {
            delay(1000);
        }
    }
    
    // Create queue for interrupt communication
    mpu_queue = xQueueCreate(10, sizeof(uint32_t));
    if (mpu_queue == NULL) {
        Serial.println("Failed to create queue");
        return;
    }
    Serial.println("Queue created");
    
    // Configure interrupt pin
    if (!setup_interrupt_pin()) {
        Serial.println("Failed to configure interrupt pin");
        return;
    }
    Serial.println("Interrupt pin configured");
    
    // Initialize Madgwick filter
    filter.begin(SAMPLE_RATE_HZ);
    Serial.println("Madgwick filter initialized");
    
    // Initialize timing
    lastReadTime = micros();
    
    // Create FreeRTOS task for IMU processing
    xTaskCreate(
        imu_task,              // Task function
        "IMUTask",             // Task name
        4096,                  // Stack size (words)
        NULL,                  // Task parameters
        1,                     // Task priority
        NULL                   // Task handle
    );
    
    Serial.println("IMU task created");
    Serial.println("System ready!");
}

// ----- ARDUINO MAIN LOOP -----
void loop() {
    // Main loop is free for other tasks
    // IMU processing is handled by FreeRTOS task
    delay(1000); // Small delay to prevent watchdog reset
}

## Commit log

2025-10-13 deciding components
    [Chassi.SLDPRT, GY_91.SLDPRT, N20_Mount.step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]
2025-10-14 basic assembly and basic generated urdf
    [Chassi.SLDPRT, LD14P_Link.STL, Mount_Link_BL.STL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]
2025-10-14 added plugin for lidar, imu and skid steering drive
    [rover.urdf]
2025-10-14 adding codes for encoder and mpu9250
    [Chassi.SLDPRT, GY_91.SLDPRT, N20_Mount.SLDPRT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]
2025-10-14 micro ros not building on platformio/esp-idf, only arduino
2025-10-14 adapting to arduino framework
2025-10-14 adding LM2596 step down
    [LM2596.SLDPRT]
2025-10-14 adding SDF model to ROS2
    [LD14P_Link.STL, Mount_Link_BL.STL, Mount_Link_BR.STL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]
2025-10-15 sdf working with texture
    [rover.sdf]
2025-10-15 urdf working with texture
    [rover.urdf]
2025-10-15 adding walls and furniture do simulate a house
    [rover.sdf]
2025-10-19 colcon ignore to other projects not related to ros2; creating package for gazebo harmonic
    [LD14P_Link.STL, Mount_Link_BL.STL, Mount_Link_BR.STL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]
2025-10-19 fixing imu frame
    [model.sdf]
2025-10-20 improving imu code; joining imu and encoder
2025-10-23 adding camera transmit; improving some aesthetic components
2025-10-23 adding battery percentage and current
2025-10-23 dont know how to install docker on this board
2025-11-03 starting electronic board
2025-11-28 finishing schematics
2025-11-28 battery and ina219 new codes; tb6612fng and mpu6050 pin fixes
    [MPU6050.cpp, MPU9250.cpp, battery.ino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]
2025-11-28 adding vl6180x reading with interrupt
